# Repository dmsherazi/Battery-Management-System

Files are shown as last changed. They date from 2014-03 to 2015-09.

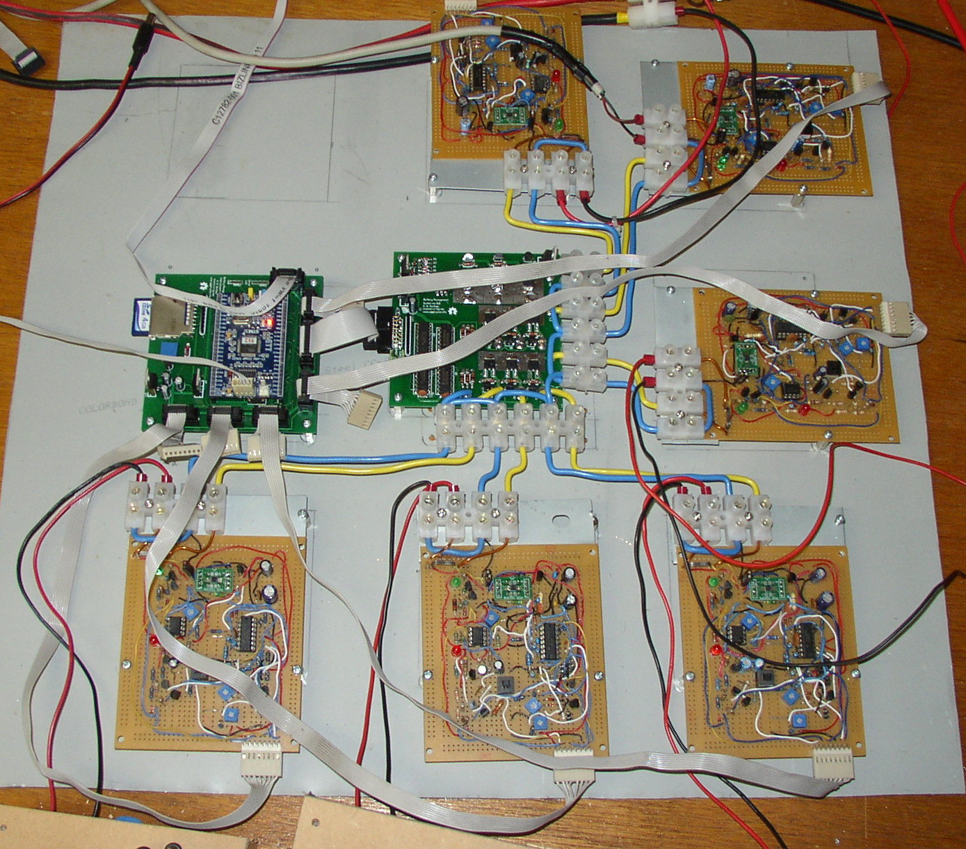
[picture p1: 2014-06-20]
Battery-Management-System-prototype-v1.jpg

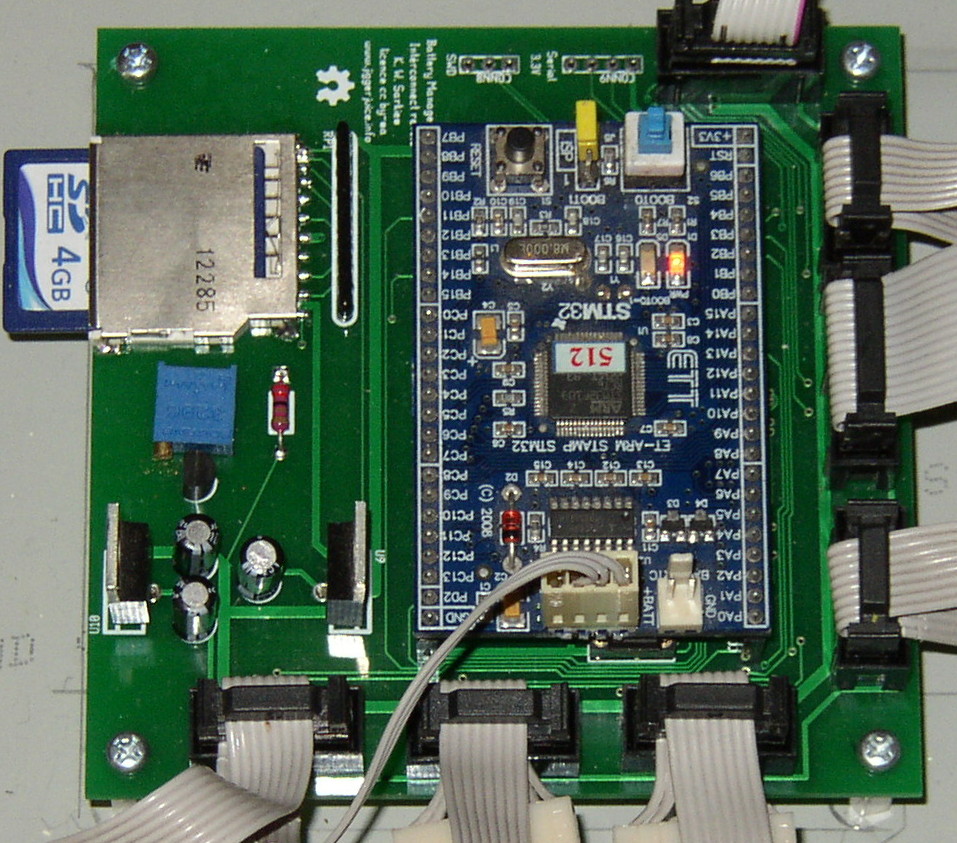
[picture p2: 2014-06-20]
gEDA-interconnect/interconnect-photo.jpg

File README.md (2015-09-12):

Battery Management System
-------------------------

This project provides software for monitoring, control and charging of batteries
for a solar powered installation.

The motivation to build this arose from the poor performance, lack of
adequate control, lack of configuration for different battery types, and poor
user interface of commercially available BMS, at least for those reasonably
priced.

The system allows for up to three batteries to be managed separately. This
ensures that failed batteries may be isolated without adversely affecting the
other batteries, as could happen if batteries were connected in parallel. Also
note that if batteries were connected in parallel, the same type and age of
battery must be used, which would necessitate changing all batteries if one were
to fail.

The system also allows for up to two loads so that critical low current loads
may be kept running after high current loads are disconnected in the event
that all batteries fall to critically low charge levels.

The system uses several methods of tracking the State of Charge of each battery,
This is a notoriously difficult parameter to estimate. In a system with three
batteries one may be isolated long enough to allow the terminal voltage to
settle to a level that will allow SoC to be computed accurately.

In the long term it is intended to allow a variety of configurations for
charging and monitoring of batteries:

1. The common three phase charger is provided using PWM to reduce the voltage
   in the absorption phase. In float phase the charger is disconnected until the
   terminal voltage drops to a threshold value. Equalization is not provided.

2. An algorithm based on Interrupted Charge Control (ICC) is also provided to
   place batteries in rest when they have reached the gassing voltage and there
   are other batteries to be charged. This has advantages of:
   (a) better utilization of the charger among the batteries,
   (b) low EMI,
   (c) reduced gas generation.

A wide range of state information is stored on a removable memory, and also
transmitted over a serial link to allow a GUI to display the state accurately
and in detail.

A GUI is provided to allow control and observation of operations. The GUI has
been provided also on a BeagleBone Black card with a LCD touchscreen. This
is suitable for wall installation and draws very low power. For wireless
communications, XBees placed in point-point AT serial mode were successful.

Each of the six interfaces has a hardware overcurrent circuit breaker and low
voltage detector, as well as providing current and voltage measurements.

A central controller based on STM32F103 controls all interfaces and the MOSFET
switches directly. Hardware signals for overcurrent and low voltage are applied
directly to the MOSFET switches for rapid disconnect.

A data processing program is also provided to generate reports of various types
from the recorded performance data.

More information is available on:

http://www.jiggerjuice.info/electronics/projects/solarbms/solarbms-overview.html

(c) K. Sarkies 12/09/2015

TODO

1. Improvement of MOSFET switch drivers to reduce EMI at higher rates.
2. MPPT regulator for the panel.

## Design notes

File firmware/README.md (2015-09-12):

Battery Management System Firmware
Version: 1.00
----------------------------------

The firmware is written for an STM32F103 ARM Cortex M3 microcontroller and uses
specific hardware published here.

The firmware uses libopencm3 for hardware drivers, FreeRTOS for task management
and ChaN FatFs for managing the local storage filesystem, along with an
adaption of the driver code by Martin Thomas for SDSC/MMC SPI drivers to
incorporate libopencm3 and FreeRTOS.

Several tasks are defined to manage:

- command and data communications,
- storage,
- battery state monitoring,
- charge control,
- measurement,
- program execution watchdog and error recovery.

It is designed to be adapted to allow CANopen to manage communications with an
external PC, in case the project is further developed.

The hardware component values set the various scaling factors for voltages and
currents, and these may change for different hardware versions.

Three versions are here represented. Each refers to slightly different
voltage and current scales in the measurement header for the interface PCB
version. Currently version 3 is being used and is the default.
It is compiled with 'make VERSION=x' where x = 2 or 3. Version 1 is obsolete.

The charger algorithm is referred to as "Pulse Charge". This aims to avoid the
PWM switching needed to maintain a constant absorption phase voltage, which
reduces EMI problems and also reduces overcharging by keeping the battery charge
voltages as low as possible. The Pulse Charge algorithm is an adaptation of 
the Interrupted Charge Control, Intermittent Charge, and Three Phase algorithms
reported in the literature, providing efficient and independent charging of
multiple batteries from an uncontrolled variable power source such as that found
in solar and aeolian systems.

More information is available on:

http://www.jiggerjuice.info/electronics/projects/solarbms/solarbms-software.html

(c) K. Sarkies 12/09/2015

BUGS

1. The file directory list command results in very slow transmission, about one
   entry per second.
2. File dates are sometimes wrong.
3. Auto tracker often makes odd decisions, such as placing load on a low battery
   or charging a higher battery.

TODO

1. Firmware upload - from within the program. Base on stm32flash.
2. Comms - test queue space available for each data message to send.
3. File - add file info (date) to GUI.
4. Measurement - Increase switching speed to 25kHz. May need hardware changes.

BUGS

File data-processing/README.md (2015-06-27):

Battery Management System Data Processing
-----------------------------------------

Provides a GUI for analysing data text files generated by the BMS and also by
the BMS GUI. These are csv records consisting of an ID and several fields of
associated data.

The program scans the file for start and end time, and extracts a list of
record types. The user can then request a number of performance measures over
a specified time interval:

- average currents to allow analysis of energy budget.
- extracted measures with average, peak or sample within a subinterval, to a csv
  file for plotting.
- Split a large file into day files and merge with previous set of day files.
- Show some basic plots of battery and module currents and battery voltages.

QWT must be installed and the .pro file modified if necessary to point to it.

(c) K. Sarkies 31/08/2014

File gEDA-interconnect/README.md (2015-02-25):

Battery Management System Interconnect
--------------------------------------

PCB for the interconnection of all interfaces and the switch electronics.

The switch provides power for the electronics. This is converted to the 3.3V
needed and is distributed to all interfaces. A couple of digital ssi gates are
used to disconnect switches when the interfaces signal overcurrent or low
voltage. The former are only used for the loads and the latter only for the
solar module. The batteries are not disconnected on overload (although the
firmware could disconnect them) as the loads will be the cause of such
overcurrents and the disconnection of batteries would be redundant. There is no
protection for internal faults that could overload the batteries.

There is an interface for logic level serial connection for use with an RS232
adapter, and a JTAG (SWI) debug connector. If this debug is used, the firmware
must be recompiled and reloaded to prevent the program capturing the JTAG pins
(this disables some software overcurrent/overvoltage detection).

The PCB has a 50 pin socket for the ET-STAMP-STM32 module from Futurlec. 25
pin SIL headers can also be obtained from them to make up a plug-in socket.

A schematic for an on-board STM32F processor is also given here, but this is not
used for this particular PCB version.

(c) K. Sarkies 02/04/2014

Version
0.1 - 24/2/2015 Add jumper and pullup so that overload cutout on panel can be
      disabled.

Todo:
1. Redesign card with on-board processor.

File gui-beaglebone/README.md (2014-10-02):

Battery Management System GUI for BeagleBone Touch Screen
---------------------------------------------------------

This is a cut-down version of the GUI for PC intended for use with a BeagleBone
touch screen for field monitoring and configuration of the BMS.

It only connects via serial (directly or using a serial to USB adapter).

To compile this program, ensure that QT4 is installed on the BeagleBone and
also that qextserialport has been downloaded and unzipped into a suitable
directory. It doesn't need to be compiled or installed, as the GUI will
incorporate it directly into the compile and link procedure.

The file power-management.pro must be modified to point to the directory
holding qextserialport.

More information is available on:

http://www.jiggerjuice.info/electronics/projects/solarbms/solarbms-gui.html

(c) K. Sarkies 29/09/2014

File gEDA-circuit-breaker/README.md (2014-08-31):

Battery Management System Circuit Breaker
-----------------------------------------

PCB for the interfaces between the external power sources and loads, and the
internal switch.

The current passes through a current sense resistor, and voltage is measured
with an offset differential amplifier, but there is no direct on-board
connection between the power and circuit commons. This is commoned elsewhere
(in the switch).

The circuit breaker passes a signal back to the interconnect board where it
is used for hardware isolation of the particular switch. For this reason the
correct power source and circuit interfaces must be used together, otherwise
the circuit breaker will be ineffective. Similarly for the low voltage
detection. The circuit breaker is based on those proposed by R Paisley
http://home.cogeco.ca/~rpaisley4/CircuitBreaker05.html

(c) K. Sarkies 31/08/2014

TODO:

1. The reference voltage to the current monitor is taken from the 2.5V
reference for the voltage measurement circuit. However this latter uses the
battery ground rather than the local ground, and a small bias voltage can
be present. Ideally the current monitor should have its own reference voltage.

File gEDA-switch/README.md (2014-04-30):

Battery Management System Switch
--------------------------------

PCB for the MOSFET switch matrix. This replaces the Kicad version.

Digital circuitry ensures that no two batteries are connected together, which
could cause damage if the state of charge differs significantly.

A diode matrix is used to provide power for the electronics. It ensures that
power is taken from the loads, or from the batteries if the loads are not
connected. This enables the firmware to keep track of the current drawn by
the local electronics.

The MOSFETs are driven by simple BJT-resistor drivers. This results in quite
slow switching speeds. There may be a need for faster switching e.g. high speed
PWM to reduce EMI. In this case the circuit needs to be modified to use better
drivers.

Special footprints have been created for the MOSFETs to provide an oversized
two-sided drain pad with plated through holes to assist in heat dissipation. The
load switches have common drains and the shared heatsink is therefore smaller.

(c) K. Sarkies 26/04/2014

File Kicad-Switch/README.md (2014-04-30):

Battery Management System Switch
--------------------------------

PCB for the MOSFET switch matrix.

Digital circuitry ensures that no two batteries are connected together, which
could cause damage if the state of charge differs significantly.

A diode matrix is used to provide power for the electronics. It ensures that
power is taken from the loads, or from the batteries if the loads are not
connected. This enables the firmware to keep track of the current drawn by
the local electronics.

The MOSFETs are driven by simple BJT-resistor drivers. This results in quite
slow switching speeds. There may be a need for faster switching e.g. high speed
PWM to reduce EMI. In this case the circuit needs to be modified to use better
drivers.

There were several errors in the circuit, which have been corrected but not
tested. The board is to be replaced with the gEDA version.

In the board, load 1 is the central row of switches and the upper power
connector. Load 2 is the lower row of switches and the lower power connector.
This is the reverse of that used in the interconnect board and has been changed
in the gEDA board.

(c) K. Sarkies 26/04/2014

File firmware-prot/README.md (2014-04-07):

Battery Management System Firmware
Version: First Prototype
----------------------------------

The firmware is written for an STM32F103 ARM Cortex M3 microcontroller and uses
specific hardware published here.

The firmware uses libopencm3 for hardware drivers, FreeRTOS and ChaN FAT for
managing the local storage filesystem.

Several tasks are defined to manage:

- command and data communications,
- storage,
- battery state monitoring,
- charge control,
- measurement,
- program execution watchdog and error recovery.

It is designed to use CANopen to manage communications with an external PC, in
case the project is further developed.

The hardware component values set the various scaling factors for voltages and
currents, and these may change for different hardware versions.

(c) K. Sarkies 15/03/2014

TODO

1. Firmware upload - from within the program. Base on stm32flash
2. Comms - test queue space available for each data message to send.
4. Measurement - Increase switching speed to 25kHz. May need hardware changes.
5. Charger - add acceleration to pull overvoltage back quickly.
6. Time - fix date setting.
7. Comms - additional commands for more configuration options.
8. Comms - by default do not send messages until instructed.

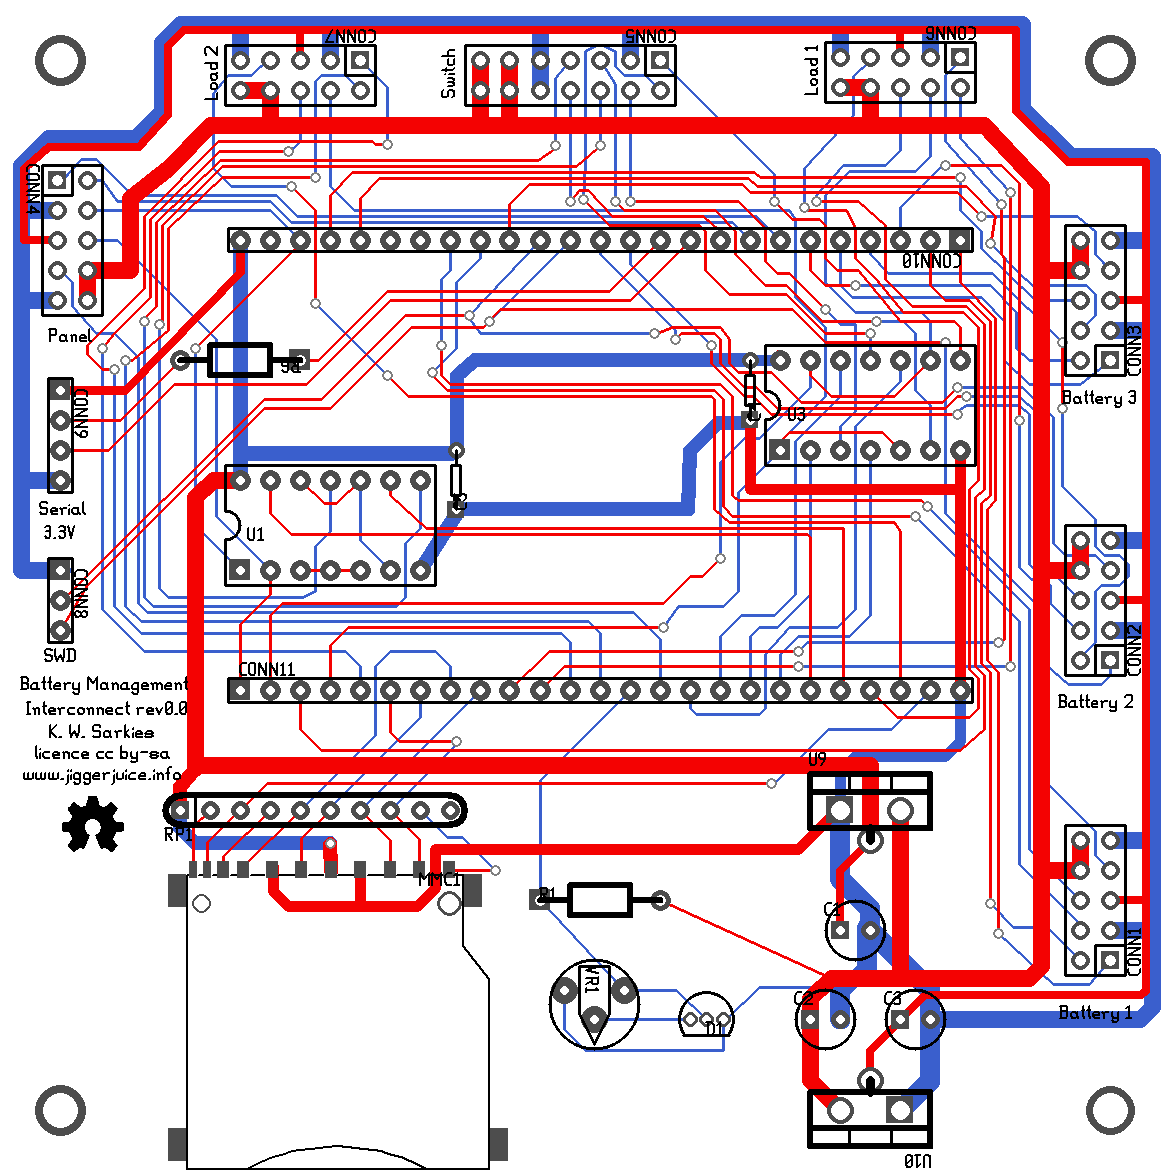
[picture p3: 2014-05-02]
gEDA-interconnect/interconnect-pcb.png

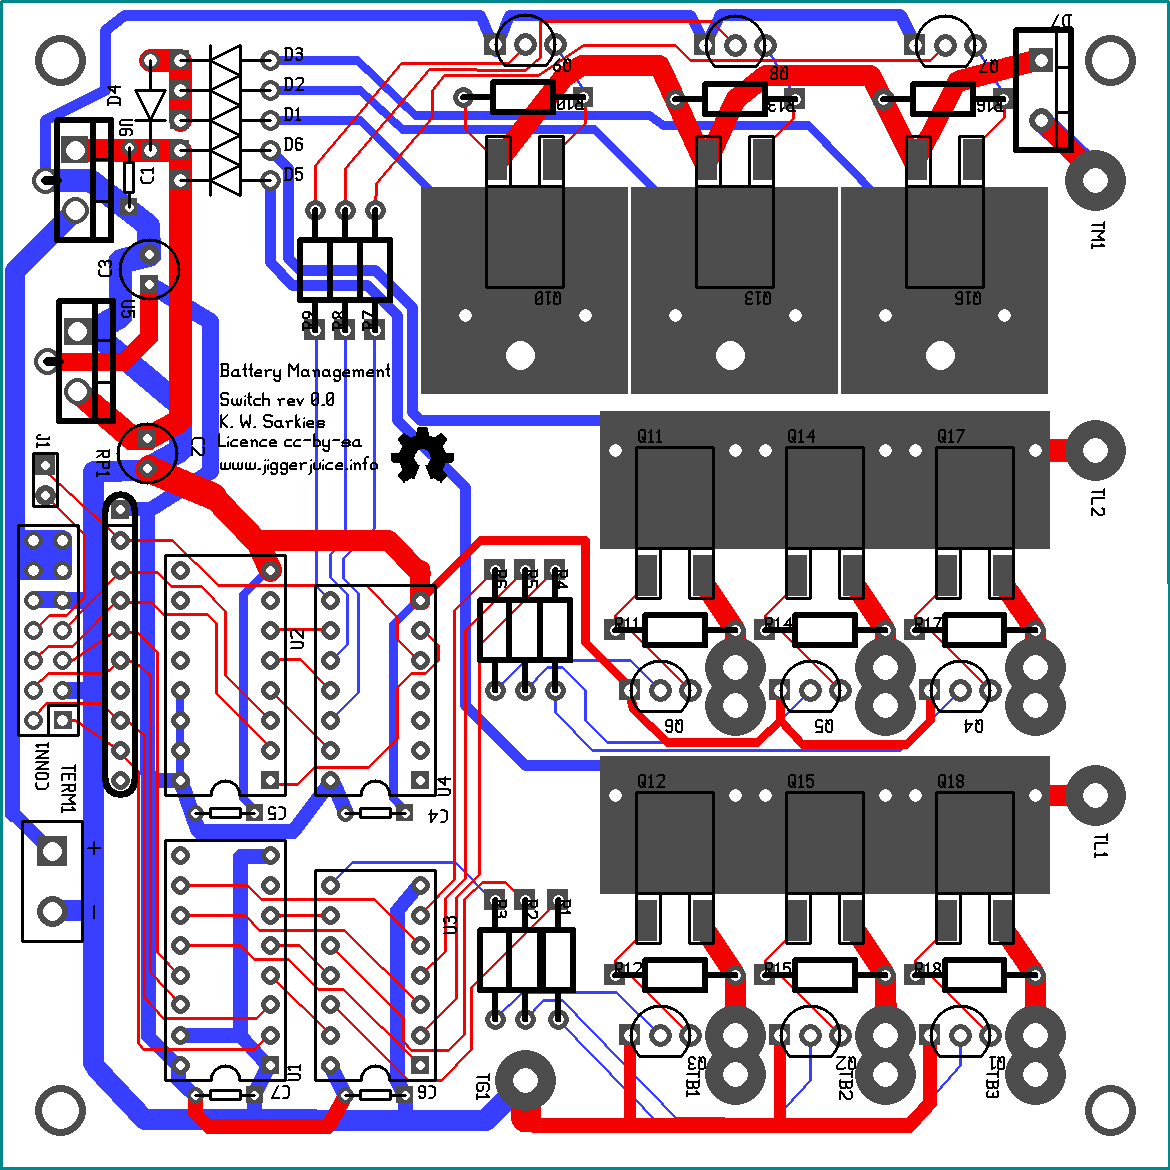
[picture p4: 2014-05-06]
gEDA-switch/switch-pcb.png

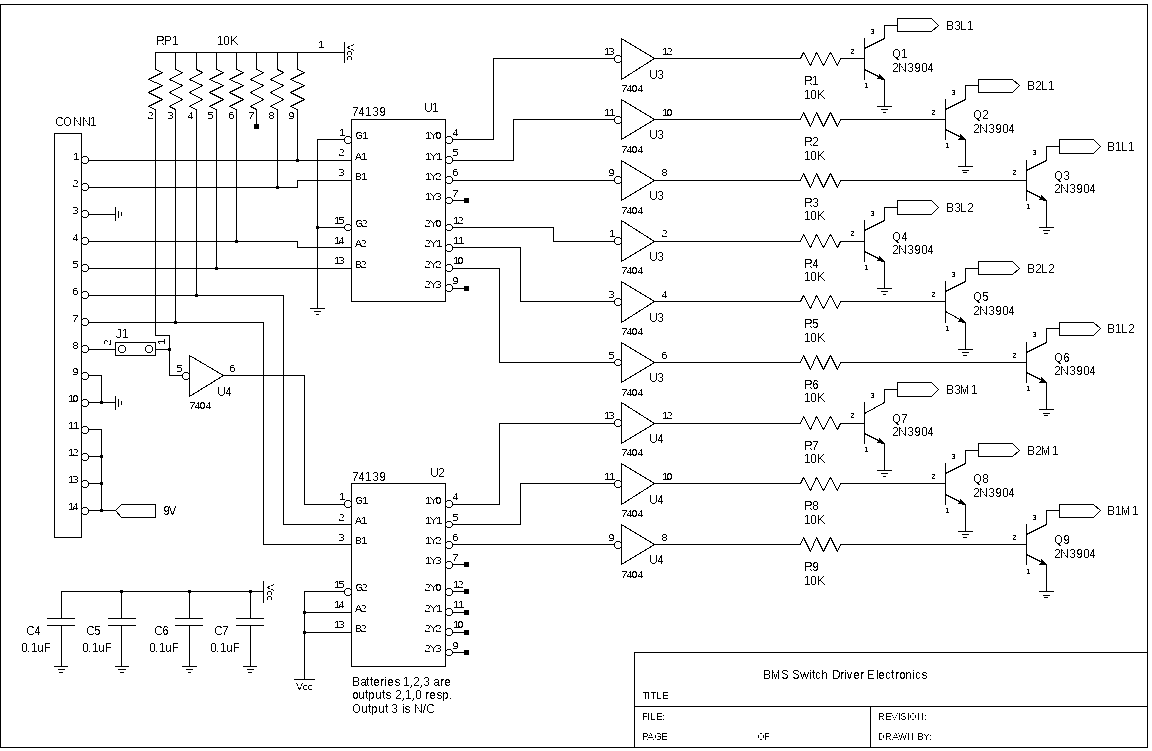
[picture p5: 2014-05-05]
gEDA-switch/switch-ssi.png

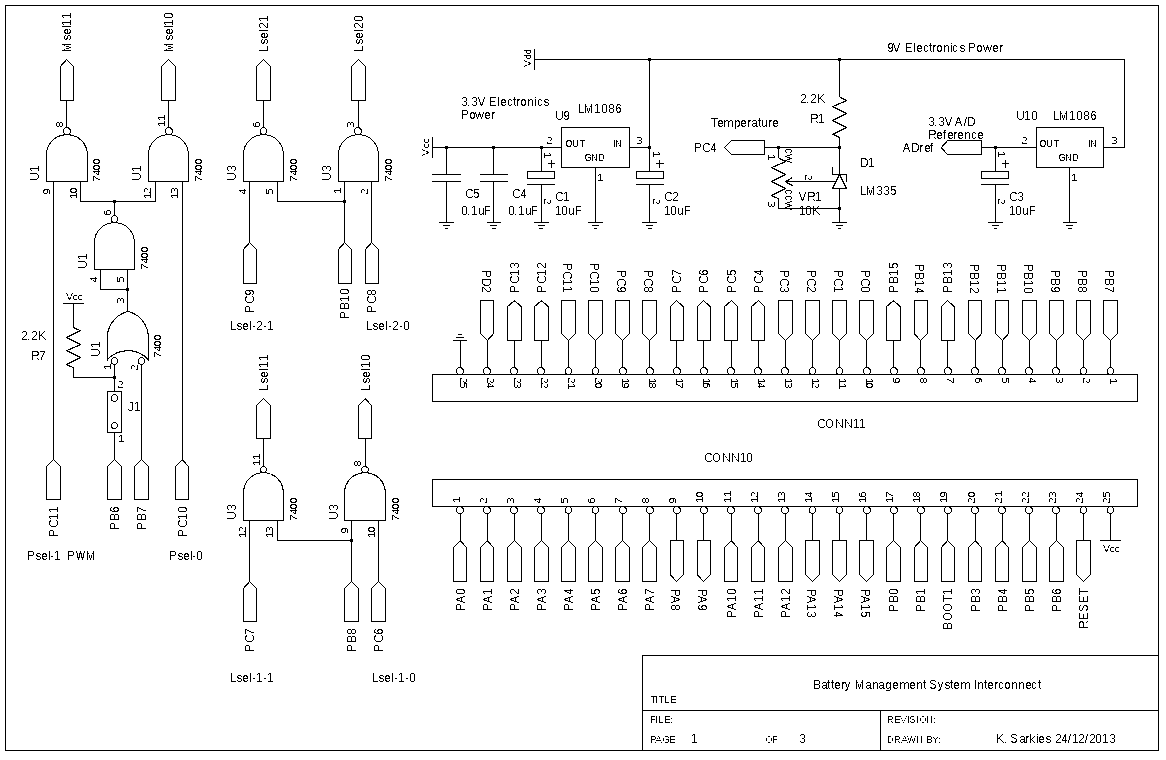
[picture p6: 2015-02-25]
gEDA-interconnect/interconnect-ssi.png

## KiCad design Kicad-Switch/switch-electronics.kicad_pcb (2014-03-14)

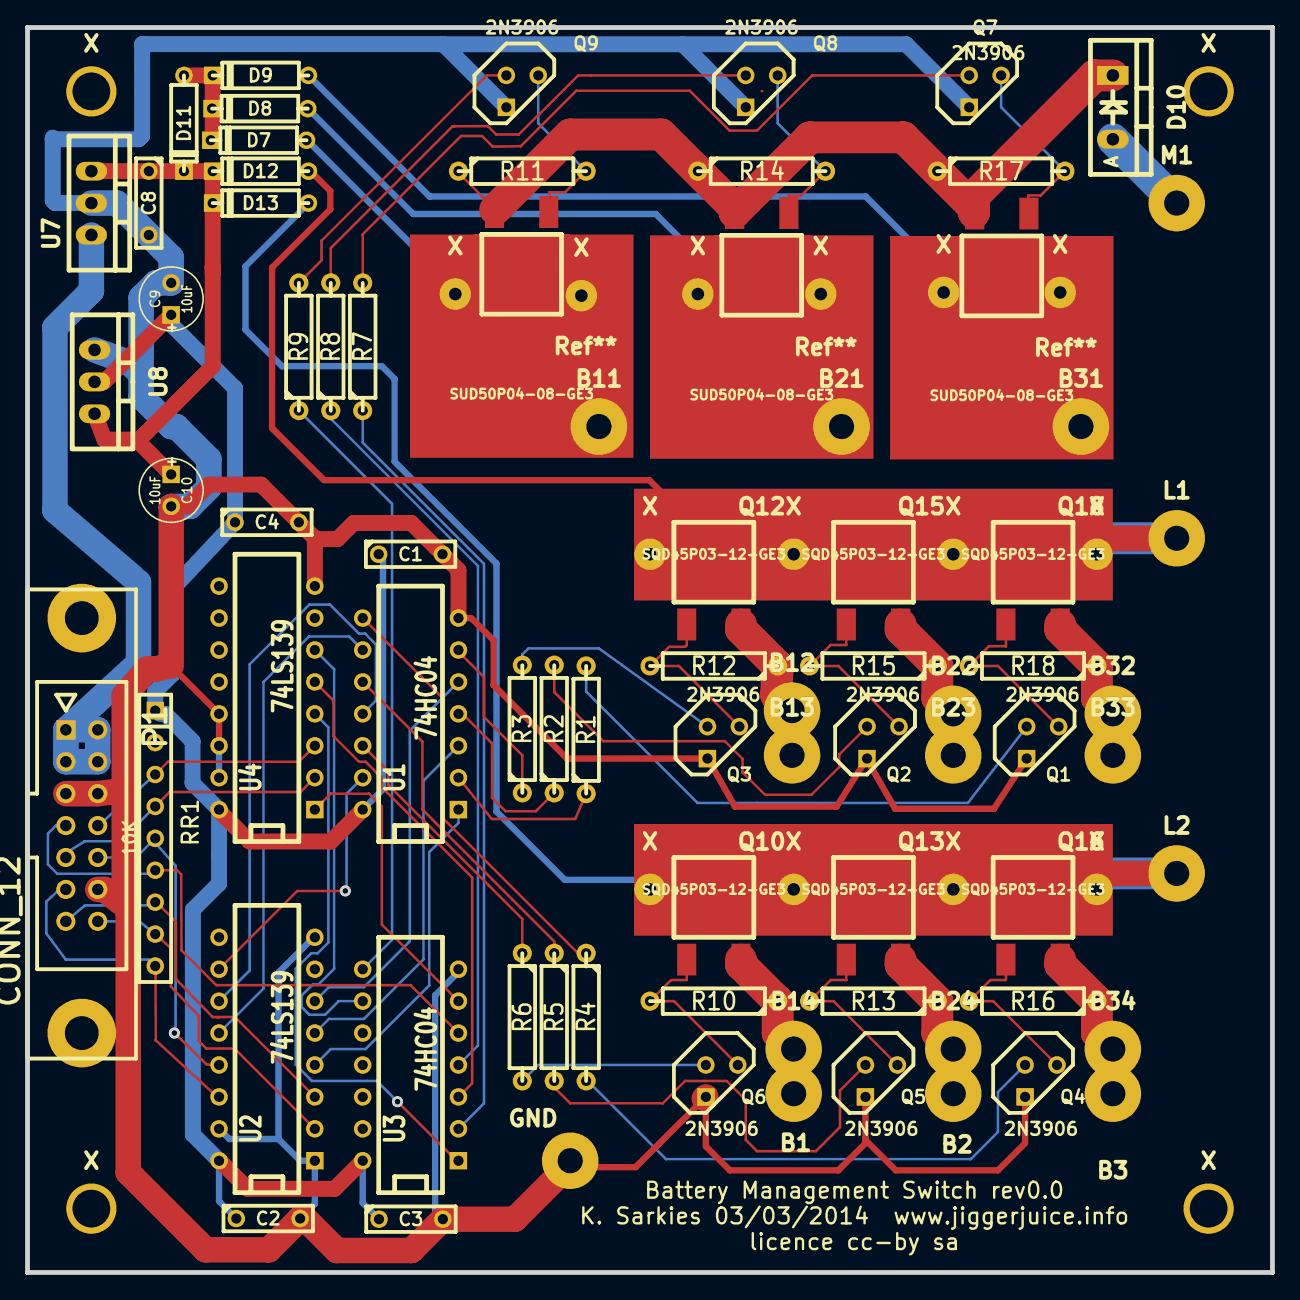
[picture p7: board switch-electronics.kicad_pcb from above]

Board: 2 copper layers, 99.1 x 99.1 mm, 95 parts (0 on the bottom side), 59 nets.

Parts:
B1, B2, B3, B11, B12, B13, B14, B21, B22, B23, B24, B31, B32, B33, B34: CONN_1; SolderWirePad_single_2mmDrill
C1, C2, C3, C4, C8: 0.1uF; C2
C9, C10: 10uF; C1V5
D7, D8, D9, D11: 1N4701; D3
D10: MBR1645; Diode_TO-220_Vertical
D12, D13: 1N5819; D3
GND: CONN_1; SolderWirePad_single_2mmDrill
L1, L2: CONN_1; SolderWirePad_single_2mmDrill
M1: CONN_1; SolderWirePad_single_2mmDrill
P1: CONN_12; he10-14d
Q1, Q2, Q3, Q4, Q5, Q6, Q7, Q8, Q9: 2N3906; TO92-CBE
Q10, Q12, Q13, Q15, Q16, Q18: SQD45P03-12-GE3; TO252-HS-S
R1, R2, R3, R4, R5, R6, R7, R8, R9: 10K; R4
R10, R11, R12, R13, R14, R15, R16, R17, R18: 1K; R4
RR1: 10K; r_pack8
Ref**: SUD50P04-08-GE3; TO252-HS
Ref**#2, Ref**#3: SUD50P04-08-GE3; TO252-HS
U1, U3: 74HC04; DIP-14__300
U2, U4: 74LS139; DIP-16__300
U7: LM7809CT; TO-220_Neutral123_Vertical
U8: LM1084IT-3.3/NOPB; TO-220_Neutral123_Vertical
X: SolderWirePad_single_2mmDrill
X#2, X#3, X#4: SolderWirePad_single_2mmDrill
X#5, X#6, X#7, X#8, X#9, X#10, X#11, X#12, X#13, X#14, X#15, X#16, X#17, X#18: SolderWirePad_single_1mmDrill

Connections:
9V: P1.11, P1.12, U7.3
B1L1: Q3.C, Q12.G, R12.2
B1L2: Q6.C, Q10.G, R10.2
B1M1: Q9.C, R11.2
B2L1: Q2.C, Q15.G, R15.2
B2L2: Q5.C, Q13.G, R13.2
B2M1: Q8.C, R14.2
B3L1: Q1.C, Q18.G, R18.2
B3L2: Q4.C, Q16.G, R16.2
B3M1: Q7.C, R17.2
GND: C1.2, C2.2, C3.2, C4.2, C8.2, C9.2, C10.2, GND.1, P1.3, P1.9, P1.10, Q1.E, Q2.E, Q3.E, Q4.E, Q5.E, Q6.E, Q7.E, Q8.E, Q9.E, U1.7, U2.1, U2.8, U2.15, U3.7, U4.8, U4.13, U4.14, U4.15, U7.2, U8.1
L1.0: P1.1, RR1.8, U2.3
L1.1: P1.2, RR1.7, U2.2
L2.0: P1.4, RR1.6, U2.13
L2.1: P1.5, RR1.5, U2.14
M1.0: P1.6, RR1.4, U4.3
M1.1: P1.7, RR1.3, U4.2
unnamed: B1.1, R10.1
unnamed: B2.1, R13.1
unnamed: B3.1, R16.1
unnamed: C8.1, C10.1, D11.2, D12.2, D13.2, U7.1, U8.3
unnamed: D7.1, R12.1
unnamed: D8.1, R15.1
unnamed: D9.1, R18.1
unnamed: D10.1, M1.1
unnamed: D10.2, R11.1
unnamed: D7.2, D8.2, D9.2, D11.1
unnamed: D12.1, L1.1
unnamed: D13.1, L2.1
unnamed: Q1.B, R1.2
unnamed: Q2.B, R2.2
unnamed: Q3.B, R3.2
unnamed: Q4.B, R4.2
unnamed: Q5.B, R5.2
unnamed: Q6.B, R6.2
unnamed: Q7.B, R7.2
unnamed: Q8.B, R8.2
unnamed: Q9.B, R9.2
unnamed: R1.1, U1.2
unnamed: R2.1, U1.4
unnamed: R3.1, U1.6
unnamed: R4.1, U1.8
unnamed: R5.1, U1.10
unnamed: R6.1, U1.12
unnamed: R7.1, U3.2
unnamed: R8.1, U3.4
unnamed: R9.1, U3.8
unnamed: U1.1, U2.4
unnamed: U1.3, U2.5
unnamed: U1.5, U2.6
unnamed: U1.9, U2.12
unnamed: U1.11, U2.11
unnamed: U1.13, U2.10
unnamed: U3.1, U4.4
unnamed: U3.3, U4.5
unnamed: U3.6, U4.1
unnamed: U3.9, U4.6
PWM: P1.8, RR1.2, U3.5
VCC: C1.1, C2.1, C3.1, C4.1, C9.1, RR1.1, U1.14, U2.16, U3.14, U4.16, U8.2

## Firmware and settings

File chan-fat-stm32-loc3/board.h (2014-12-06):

/* ChaN's FAT Disk I/O library.

MODIFIED FILE

Defines for the microcontroller board used.

The file is substantially that provided by Martin Thomas in his STM driver
contribution to the ChaN FAT library. It has been modified for libopencm3.

Only the two ET boards have been tested.

*/
/* Copyright (c) 2010, Martin Thomas, ChaN
   Copyright (c) 2013 Ken Sarkies
   All rights reserved.

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
  THIS SOFTWARE IS PROVIDED BY THE COPYRIGHT HOLDERS AND CONTRIBUTORS "AS IS"
  AND ANY EXPRESS OR IMPLIED WARRANTIES, INCLUDING, BUT NOT LIMITED TO, THE
  IMPLIED WARRANTIES OF MERCHANTABILITY AND FITNESS FOR A PARTICULAR PURPOSE
  ARE DISCLAIMED. IN NO EVENT SHALL THE COPYRIGHT OWNER OR CONTRIBUTORS BE
  LIABLE FOR ANY DIRECT, INDIRECT, INCIDENTAL, SPECIAL, EXEMPLARY, OR
  CONSEQUENTIAL DAMAGES (INCLUDING, BUT NOT LIMITED TO, PROCUREMENT OF
  SUBSTITUTE GOODS OR SERVICES; LOSS OF USE, DATA, OR PROFITS; OR BUSINESS
  INTERRUPTION) HOWEVER CAUSED AND ON ANY THEORY OF LIABILITY, WHETHER IN
  CONTRACT, STRICT LIABILITY, OR TORT (INCLUDING NEGLIGENCE OR OTHERWISE)
  ARISING IN ANY WAY OUT OF THE USE OF THIS SOFTWARE, EVEN IF ADVISED OF THE
  POSSIBILITY OF SUCH DAMAGE. */

#ifndef BOARD_H_
#define BOARD_H_

/* set to 1 to provide a disk_ioctrl function even if not needed by the FatFs */
#define STM32_SD_DISK_IOCTRL_FORCE      0

//#define STM32_SD_USE_DMA

//#define USE_ET_STAMP_STM32
//#define USE_ET_STM32F103
//#define USE_EK_STM32F
//#define USE_STM32_P103
//#define USE_MINI_STM32

#if defined USE_ET_STM32F103
 #define CARD_SUPPLY_SWITCHABLE   0
 #define SOCKET_WP_CONNECTED      1 /* write-protect socket-switch */
 #define SOCKET_CP_CONNECTED      0 /* card-present socket-switch (clashes with USART1 on this board) */
 #define GPIO_PORT_WP             GPIOC
 #define RCC_GPIO                 RCC_APB2ENR
 #define RCC_GPIO_PORT_WP         RCC_APB2ENR_IOPCEN
 #define GPIOWP                   GPIO6
 #define GPIO_MODE_WP             GPIO_CNF_INPUT_FLOAT /* external resistor */
 #define GPIO_PORT_CP             GPIOA
 #define RCC_GPIO_PORT_CP         RCC_APB2ENR_IOPAEN
 #define GPIOCP                   GPIO8
 #define GPIO_MODE_CP             GPIO_CNF_INPUT_FLOAT /* external resistor */
 #define GPIO_PORT_CS             GPIOA
 #define RCC_GPIO_PORT_CS         RCC_APB2ENR_IOPAEN
 #define GPIOCS                   GPIO4
 #define SPI_SD                   SPI1
 #define DMA_CHANNEL_SPI_SD_RX    DMA_CHANNEL2
 #define DMA_CHANNEL_SPI_SD_TX    DMA_CHANNEL3
 #define DMA_FLAG_SPI_SD_TC_RX    DMA_TCIF
 #define DMA_FLAG_SPI_SD_TC_TX    DMA_TCIF
 #define GPIO_PORT_SPI_SD         GPIOA
 #define GPIOSPI_SD_SCK           GPIO5
 #define GPIOSPI_SD_MISO          GPIO6
 #define GPIOSPI_SD_MOSI          GPIO7
 #define RCC_SPI                  RCC_APB2ENR
 #define RCC_SPI_SD               RCC_APB2ENR_SPI1EN
/* - for SPI1 and full-speed APB2: 72MHz/4 */
 #define SPI_BaudRatePrescaler_fast    SPI_CR1_BR_FPCLK_DIV_4
 #define SPI_BaudRatePrescaler_slow    SPI_CR1_BR_FPCLK_DIV_256

#elif defined USE_ET_STAMP_STM32
 #define CARD_SUPPLY_SWITCHABLE   0
 #define SOCKET_WP_CONNECTED      0 /* write-protect socket-switch */
 #define SOCKET_CP_CONNECTED      0 /* card-present socket-switch (clashes with USART1 on this board) */
 #define GPIO_PORT_WP             GPIOB
 #define RCC_GPIO                 RCC_APB2ENR
 #define RCC_GPIO_PORT_WP         RCC_APB2ENR_IOPBEN
 #define GPIOWP                   GPIO11
 #define GPIO_MODE_WP             GPIO_CNF_INPUT_FLOAT /* external resistor */
 #define GPIO_PORT_CP             GPIOB
 #define RCC_GPIO_PORT_CP         RCC_APB2ENR_IOPBEN
 #define GPIOCP                   GPIO10
 #define GPIO_MODE_CP             GPIO_CNF_INPUT_FLOAT /* external resistor */
 #define GPIO_PORT_CS             GPIOB
 #define RCC_GPIO_PORT_CS         RCC_APB2ENR_IOPBEN
 #define GPIOCS                   GPIO12
 #define SPI_SD                   SPI2
 #define DMA_CHANNEL_SPI_SD_RX    DMA_CHANNEL4
 #define DMA_CHANNEL_SPI_SD_TX    DMA_CHANNEL5
 #define DMA_FLAG_SPI_SD_TC_RX    DMA_TCIF
 #define DMA_FLAG_SPI_SD_TC_TX    DMA_TCIF
 #define GPIO_PORT_SPI_SD         GPIOB
 #define GPIOSPI_SD_SCK           GPIO13
 #define GPIOSPI_SD_MISO          GPIO14
 #define GPIOSPI_SD_MOSI          GPIO15
 #define RCC_SPI                  RCC_APB1ENR
 #define RCC_SPI_SD               RCC_APB1ENR_SPI2EN

/* - for SPI2 and full-speed APB1: 36MHz/2 */
 #define SPI_BaudRatePrescaler_fast    SPI_CR1_BR_FPCLK_DIV_4
 #define SPI_BaudRatePrescaler_slow    SPI_CR1_BR_FPCLK_DIV_256
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

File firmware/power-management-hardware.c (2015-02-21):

/* STM32F1 Power Management for Solar Power

Hardware Setup

This configures all peripherals for the program and provides some
convenience functions for accessing the hardware.

Along with the file board-defs.h that provides specific defines for the
processor board in use, this file abstracts the hardware from the rest
of the program and allows rapid adaption to other board archictectures.

Note that the STM32F series of ARM microcontrollers are used because of
their provision of 12 bit A/D.

Flash write code adapted from code by Damian Miller.

Initial 29 September 2013
*/

/*
 * This file is part of the battery-management-system project.
 *
 * Copyright 2013 K. Sarkies <ksarkies@internode.on.net>
 *
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
 * You should have received a copy of the GNU Lesser General Public License
 * along with this program.  If not, see <http://www.gnu.org/licenses/>.
 */

/* Set this define if the SWD debug is to be used. It will disable some ports
so must be commented out for normal use. */
//#define USE_SWD

#include <stdint.h>
#include <stdbool.h>

#include "power-management-board-defs.h"
#include "power-management-hardware.h"

/* libopencm3 driver includes */
#include <libopencm3/stm32/iwdg.h>
#include <libopencm3/stm32/rcc.h>
#include <libopencm3/stm32/rtc.h>
#include <libopencm3/stm32/adc.h>
#include <libopencm3/stm32/gpio.h>
#include <libopencm3/stm32/timer.h>
#include <libopencm3/stm32/dma.h>
#include <libopencm3/stm32/usart.h>
#include <libopencm3/stm32/flash.h>
#include <libopencm3/cm3/nvic.h>
#include <libopencm3/cm3/scb.h>
#include <libopencm3/cm3/systick.h>

/* Scheduler includes. */
#include "FreeRTOS.h"
#include "queue.h"
#include "semphr.h"

extern uint32_t __configBlockStart;
extern uint32_t __configBlockEnd;

/* Local Prototypes */
static void adcSetup(void);
static void dmaAdcSetup(void);
static void iwdgSetup(void);
static void gpioSetup(void);
static void usartSetup(void);
static void clockSetup(void);
static void systickSetup();
static void pwmSetup(void);

/* Local Variables */
static uint8_t pwmCount;
static uint32_t v[NUM_CHANNEL]; /* Buffer used by DMA to dump A/D conversions */
static uint8_t adceoc;          /* A/D end of conversion flag */
static uint32_t lostCharacters; /* Number of characters lost due to queue full */

/* FreeRTOS queues and intercommunication variables defined in Comms */
extern xQueueHandle commsSendQueue, commsReceiveQueue, commsEmptySemaphore;

/* Time variable needed when systick is the timer */
static uint32_t timeCounter;

/* This is provided in the FAT filesystem library */
extern void disk_timerproc();

/*--------------------------------------------------------------------------*/
/** @brief Initialise the hardware

*/

void prvSetupHardware(void)
{
    clockSetup();
    gpioSetup();
    usartSetup();
    pwmSetup();
    dmaAdcSetup();
    adcSetup();
    systickSetup();
    rtc_auto_awake(LSE, 0x7fff);
    iwdgSetup();
}

/*--------------------------------------------------------------------------*/
/** @brief Return the A/D Conversion Results

Note the channel must be less than the number of channels in the A/D converter.

@param[in] uint8_t channel: A/D channel to be retrieved from the DMA buffer.
@returns uint32_t : last value measured by the A/D converter.
*/

uint32_t adcValue(uint8_t channel)
{
    if (channel > NUM_CHANNEL) return 0;
    return v[channel];
}

/*--------------------------------------------------------------------------*/
/** @brief Return and Reset the A/D End of Conversion Flag

This must be retrieved from the ISR as the hardware EOC doesn't always change
at the end of a conversion (when multiple conversions take place).

@returns uint8_t: boolean true if the flag was set; false otherwise.
*/

uint8_t adcEOC(void)
{
    if (adceoc > 0)
    {
        adceoc = 0;
        return 1;
    }
    return 0;
}

/*--------------------------------------------------------------------------*/
/** @brief Read and Return Interface Error Indicators

The indicator settings are read and combined, with battery1, battery2,
battery3, load1, load2, panel from lsb up, and overload followed by
undervoltage for each.

Each bit is zero if the indicator is on, 1 if it is off.

@returns uint16_t
*/
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

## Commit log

2014-03-14 Initial commit of hardware PCB, firmware, GUI and data processing.
    [circuit-breaker-1.sch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]
2014-03-15 Addition of watchdog task for protection and reset of tasks. Change blocking queue and semaphore calls to timeout. Message send functions now dispose of whole message if queue is full. (there is stil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
    [power-management-board-defs.h, power-management-charger.c, power-management-comms.h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]
2014-03-16 Update of READMEs with TODOs. Add watchdog reset to calibration.
2014-03-17 Add an option variable to allow a switch avoidance strategy to be used. TODO needs to be added to the GUI
    [power-management-objdic.h]
2014-03-21 Update circuit breaker pcb and schematic for voltage measurement
    [circuit-breaker-1.sch]
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2014-03-22 Further work on data processing to extract selected records. Addition to BMS GUI of battery charging limits in configure window.
2014-03-26 More features for data processing - still not ready Changes to firmware voltage limits to correct corrections back again. Corrections to battery parameter settings Correction to GUI to display newly 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
    [power-management-measurement.c, power-management-measurement.h]
2014-03-27 Addition of firmware for new PCB version,. Minor corrections to PCB on interface. Removal of extraneous files in all PCB directories
    [switch.GBL, switch.GBO, switch.GBS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]
2014-04-02 Addition of up to three debug messages to dataprocessing Correction to charger algorithm - reset to bulk when loaded and SoC<95% - incorrect test for battery too long in absorption phase - reset SoC 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
    [power-management-charger.c, power-management-monitor.h]
2014-04-07 In charger, turn off when voltage drifts too far above limit. If switch avoidance is set, use a bang-bang control. In monitor stop charging if battery in float and above 95% SoC
    In gui, fix capacity displays.
    [power-management-charger.c, power-management-monitor.h]
2014-04-07 Remove the firmware-pcb and firmware-prot directories and integrate into the firmware directory.
    Need a better way to represent the differences.
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2014-04-12 Changes to the monitor. When a battery reaches float state, deallocate the charger. Test all batteries to find a suitable one to charge. If not found, then leave the charger unallocated.
2014-04-12 Start dealing with faulty and missing batteries Define states in objdic config structure. Add comms interface to GUI. - Still need to adapt monitor code to deal with missing and faulty batteries. The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
    [power-management-objdic.h]
2014-04-15 Charger - change code to stop charging in float phase to a test on all batteries. Monitor - add more decision values Objdic - default battery types to gel for safety. GUI - Add additional indicator f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
2014-04-16 Rework missing battery detection and handling.
    [power-management-monitor.h, power-management-objdic.h]
2014-04-16 Firmware - add additional processing for 2 batteries similar to the 3 battery processing. GUI - Add missing battery features to the main screen, wiping out all display for the battery. GUI - Add extr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
    In firmware there is an outstanding issue with calibration that fails to determine quiescent current.
2014-04-16 Bug in calibration fixed, now handles the 2 battery case OK.
2014-04-23 Update circuit breaker PCB to add limiting zener to voltage measurement input, protection resistors to voltage and current measurement output, change current monitor reference from 3.3V external to 2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
    [circuit-breaker-1.sch, circuit-breaker-2.sch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]
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2014-04-25 Layout of gEDA-Switch to replace and correct the Kicad version. Addition of some footprints and symbols and update of footprint for Interconnect (for some reason the solder mask was not opened up on 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
    [switch-layout-sw.sch, switch-mc.sch, switch-mosfet.sch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]
2014-04-25 Modification of charger to detect when the voltage exceeds the maximum measurable voltage and to turn off the PWM.
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2014-04-25 Minor changes to remove binary files and make Kicad gerber directory.
    [bms-switch.gbl, bms-switch.gbo, bms-switch.gbr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]
2014-04-26 Completion of gEDA Switch PCB.
    [switch-mosfet.sch, switch-ssi.sch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]
2014-04-26 Update all PCBs to correct minor errors. Generate gerbers Need still to check on drill sizes, especially diodes.
    [circuit-breaker-2.sch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]
2014-04-30 Update to switch PCB for minor cosmetic adjustment Addition of circuit breaker png Minor doc changes to firmware
    Note for Kicad switch that load1 is on the top and load 2 on the bottom,
    reverse that for the interconnect.
    [switch.back.gbl, switch.backmask.gbs, switch.backsilk.gbo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]
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2014-05-02 Interconnect: create pngs Circuit breaker: change series resistor for overload/underload signals to 4.7K to reduce the low voltage. GUI: Remove line that cleared the load 2 checkbox when undervoltage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
    [circuit-breaker-2.sch]
2014-05-04 Add =/- to terminal silk screen Add terminal to switch PCB for 9V distribution.
    [switch-power.sch]
2014-05-05 Rename interconnect and switch directories Switch update simplify the layout and add some labels Circuit breaker repair symbols and footprints to remove false shorts.
    [circuit-breaker-1.sch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]
2014-05-06 Adjustments to PCB for manufacture
    [switch.back.gbl, switch.backmask.gbs, switch.backsilk.gbo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]
2014-05-07 Change monitor so that a detected missing battery has its loads removed. GUI configure allow buttons to set a battery as missing as well as not missing.
2014-05-07 The missing battery status, once set, cannot be changed back. This is done externally. The electronics will show a missing battery as present if no loads are allocated to it, therefore it cannot be i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
2014-05-08 Correct some errors. The case of numbats == 1 was not being detected so removed the cryptic addition to the if statement.
2014-05-15 Correct voltage measurement parameters for VERSION=1. Remove VERSION=1 from the duty cycle setting function: first prototype of interconnect board now obsoleted.
    [power-management-hardware.c, power-management-measurement.h]
2014-05-15 Add feature to scan all currents and print out total AH energies. Total of battery currents gives usage/charge balance. Negative load and charge currents are set to zero - these come from undervoltag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
2014-05-18 Update directory display in file module to show file size. Minor addition to circuit breaker README.
2014-05-24 Fix day error in time module Fix compile warning in measurement module Add in option to GUI to avoid switching in charge algorithm None of these are tested yet.
    [power-management-measurement.c]
2014-05-31 Major modification to charger code to incorporate the ICC algorithm as an option to the three phase algorithm.
2014-06-12 Fix bug that caused blank lines to be inserted in output when not in time range.
2014-06-12 Introduce ICC algorithm (removed from main charger module). Requires different approach to monitoring. Separate out two charger files and add switch to makefile. ICC CODE IS INCOMPLETE. PRELIMINARY O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
2014-06-14 Move generic code from charger-3ph.c to charger-common.inc to be #included As a result the computation of averaged currents and voltages is done on all batteries, even missing ones. Set the Panel swi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
    [power-management-monitor.h]
2014-06-16 Add 5V regulator as voltage reference to current monitor. Change offset resistors.
    [circuit-breaker-1.sch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]
2014-06-20 Change to circuit breaker circuit to use local current offset reference and to update voltage measurement for zero ground bias. Add photos of completed boards and prototype 1
    [circuit-breaker-1.sch]
2014-06-20 Revert charger code to just 3 phase to identify problems. Update measurement scaling factors for third amplifier configurations.
    [power-management-charger.c, power-management-measurement.h]
2014-07-06 Add tests for battery stuck in absorption phase to monitor firmware Set VERSION=3 to makefile default. New low bias voltage amplifier values.
    [power-management-charger.c]
2014-07-11 Fix bug identifying wrong battery in absorption phase and not charged. Small adjustment to lower threshold for fall out of absorption phase back to bulk.
    [power-management-charger.c]
2014-07-12 Fix array bound infringement bug when battery under charge is zero (no battery allocated)
    [power-management-charger.c]
2014-07-27 Add custom footprint to Kicad-Switch directory (even though we are not using Kicad! for the final PCBs).
2014-08-29 Correct the computeSoC function for negative SoC Add a manualSwitchSetting variable set in comms when a battery allocated manually to a panel. Fix the 3PH charger to use the manually set battery Simi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
    [power-management-charger.c, power-management-hardware.c, power-management-objdic.h]
2014-08-30 Correct bugs in ICC. Now use configuration panelSwitchSetting to store preferred battery everywhere. Change monitor to allocate loads according to battery actually charged, keeping the batteryUnderCh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
    [power-management-charger.c, power-management-monitor.h, power-management-objdic.h]
2014-08-31 Check change of charging status on all batteries, otherwise it may never change.
2014-09-01 Add feature to allow manual reset of SoC from OCV. Add feature to block serial transmission until instructed.
    [power-management-monitor.h, power-management-objdic.h]
2014-09-01 Final tweak to interface card before sending off.
    [circuit-breaker-1.sch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]
2014-09-02 Add "rest" option to charge state in data processing dump file code.
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2014-09-02 ICC algorithm set switches to turn off immediately phase changes to rest or float. Thus avoids overvoltage in the latter part of a slot after the change. Change ICC slot period to 30 seconds.
    [power-management-charger.c]
2014-09-03 Change icc boolean to charge-algorithm parameter from GUI Add files and code to support IC algorithm. Same as ICC for now. Rearrange objdic variables to ease addition of more settable parameters.
2014-09-04 Create the IC algorithm. Still to test for current to go to float stage. Add remaining variables to GUI Yet to add these to firmware.
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2014-09-11 Minor corrections to remove reference to CHARGER in makefile, and add charger.h to comms.
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2014-10-02 Remove the common charger include file and make functions shared in charger.c
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2014-10-02 Cut down version of the GUI suitable for an LCD touch display
2014-10-02 Further thoughts about pule charge algorithm. Make accumulated off time for checking excessive time in charge.
2014-10-03 Adapt gui and firmware to refer to pulse algorithm rather than IC. Fix some bugs in the algorithm.
    [power-management-charger.c, power-management-objdic.h]
2014-10-10 Fix bug that caused SoC to jump to 100% on loaded battery.
2014-10-11 Modify the pulse charge algorithm to not pass to float if the on-time is too long. Correct a sign error in a battery current assignment.
2014-10-31 Fix pulse charger to set battery to 100% SoC on change to float
    [power-management-measurement.h, power-management-monitor.h]
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2014-11-09 Change of monitor to account for rest phase. The battery under charge is now recognised in this task and is allocated directly. The charger task now merely moves the batteries between phases, and in 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
2014-11-10 Fix some problems with monitor and pulse charger. Now passes between bulk and rest phases. Still to update the 3PH and IC/ICC.
2014-11-10 In pulse charge algorithm, compute accumulated charge over the whole cycle to account for load drain.
2014-11-10 Remove the IC and ICC algorithms. The source files are left in place in case they are resurrected later, but have not been adapted to work with the firmware.
2014-11-10 Modify data processing app to give 0 for missing battery rather than a space.
2014-11-11 Remove remaining IC and ICC references and files. Add debug calls to charger-pulse.
2014-11-12 Reset pulse charge algorithm when charger voltage is below 10V.
2014-12-06 Change chan-fat-stm32-loc3 to return status at end of disk operation functions, to simplify error debug. General tidy up of docs, removal of hard tabs in firmware.
    [board.h, diskio.h, power-management-charger.c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]
2014-12-08 chan-fat-stm32-loc3: More improvements to layout and docs. Temporary debug statements to trap FatFs errors arising in physical layer.
    [sd_spi_loc3_stm32_freertos.c]
2014-12-08 Change SPI transfers to DMA Upgrade the chan-fat-10c A bit more tweaking of docs.
2014-12-08 Changed disk_timerproc call in hardware.c to trigger every 10ms instead of 1ms. left over from time when systick was thought to be 10ms. This now extends the wait timeout for SPI data by 10 times. Al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
2014-12-24 Charger algorithm changed to combine pulse and three-phase into one. References to charger control algorithm removed.
2014-12-25 Bug fixes in monitor and charging. Move absorption phase decisions to the charger, limiting the time in absorption phase and aborting it when the panel voltage drops out. Fix bug in setting SoC on ch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
    [power-management-charger.c]
2014-12-26 Corrections to charger algorithm
    [power-management-charger.c]
2014-12-27 Charger: Correction of problems with source dropout and overvoltage at the start of the absorption phase. Updated README
    [power-management-charger.c]
2014-12-27 Charger modify duty cycle on entry to absorption phase to attempt to reduce overshoot. Some name changes.
    [power-management-charger.c]
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2014-12-30 Update circuit breaker PCB to reverse regulator and correct voltage amplifier to version 3. Add symbol files.
    [circuit-breaker-1.sch, circuit-breaker-2.sch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]
2015-02-20 Change from custom RTC code to make use of glibc time functions. Added nosys.spec to linker to avoid undefined symbols. A few mods to documentation.
    [power-management-hardware.c, power-management-monitor.h]
2015-02-21 Correct some bugs in calling time.h functions.
    [power-management-hardware.c]
2015-02-25 interconnect board, added a jumper and pullup resistor so that the current overload signal from the panel can be disabled in hardware.
    [interconnect-ssi.sch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]
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2015-03-11 Add in changing the bulk current limit to the GUI, and fix small error.
2015-03-12 Include monitor and charger strategies to firmware and GUI and fix some minor errors in relation to changing monitor and charger parameters.
    [power-management-objdic.h]
2015-03-19 Fix bug in GUI that didn't set monitor and charger strategies. Minor updates to firmware to rearrange command processing for clarity. Add default charger strategy to firmware initializer.
2015-03-20 Correct bug in which SoC in GUI wasn't correctly scaled for float to bulk phase change, as well as duty cycle minimum. Add absorption phase suppression to charger in firmware.
    [power-management-charger.c, power-management-objdic.h]
2015-03-24 Firmware fix erroneous charging parameter messages.
2015-03-25 Rejig the Beaglebone display and add code to remove the cursed cursor. Change group boxes in main tab to frames. After recalibration the display works but feature size is too small. Need to use a met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
2015-05-01 Add a firmware feature to force current calibration to zero for a battery in the event it fails. Add a shutdown button to the BB gui. This relies on a file in /bin that calls the gui and then shuts d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
2015-08-17 Make the firmware replay with an ident message containing the firmware interface and board versions. The GUI now displays this in teh configuration window, Fix a makefile problem.
    [power-management-objdic.h]
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2015-09-02 A few very minor changes to different parts of the code - data processing GUI to add a tooltip - firmware to change version back to version 1 - circuit breaker schematic with unknown change
    [circuit-breaker-1.sch]
2015-09-03 Further to the startup problem for the Beaglebone GUI, added a timer to attempt to restart communications every second until they work.
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2015-09-23 Minor changes to GUI to add better instructions for calibration. Attempt to fix serial connect/disconnect, without success so far.
2015-09-29 Firmware- slight adjustment to absorption charge voltages to avoid gassing. Possible bug in computing temperature offset.
    [power-management-charger.c, power-management-objdic.h]

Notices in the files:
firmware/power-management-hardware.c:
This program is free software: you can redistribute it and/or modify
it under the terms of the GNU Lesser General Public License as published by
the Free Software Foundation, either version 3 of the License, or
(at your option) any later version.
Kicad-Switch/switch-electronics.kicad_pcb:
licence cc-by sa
